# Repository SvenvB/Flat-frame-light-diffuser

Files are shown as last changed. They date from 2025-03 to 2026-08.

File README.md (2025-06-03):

# Flat Frame Light Diffuser for the Orion SpaceProbe 130ST
A simple white light source and custom mount for capturing flat frames with the Orion SpaceProbe 130ST telescope. Most of the materials I had lying around, but you can likely build it for around **$15**.

I'm using the [Orion SpaceProbe 130ST telescope](https://www.highpointscientific.com/orion-spaceprobe-130st-short-tube-eq-reflector-telescope) with a [ZWO ASI224MC](https://www.zwoastro.com/product/zwo-asi224mc/) CMOS imaging camera, and I enjoy deep-sky imaging without breaking the bank.

While dark frames are easy to take with the dust cap on, I was looking for a convenient and budget-friendly way to make **flat frames**. I usually shoot early in the evening and don't have twilight available. While placing a white t-shirt over the telescope and using a [laptop screen](https://practicalastrophotography.com/a-brief-guide-to-calibration-frames/) is one option, I wanted a more straightforward and reusable solution. Hence, this flat frame light diffuser for the Orion SpaceProbe 130ST.

The Flat Frame Light Diffuser is operated on the same 12V battery source I use for my star-tracker.

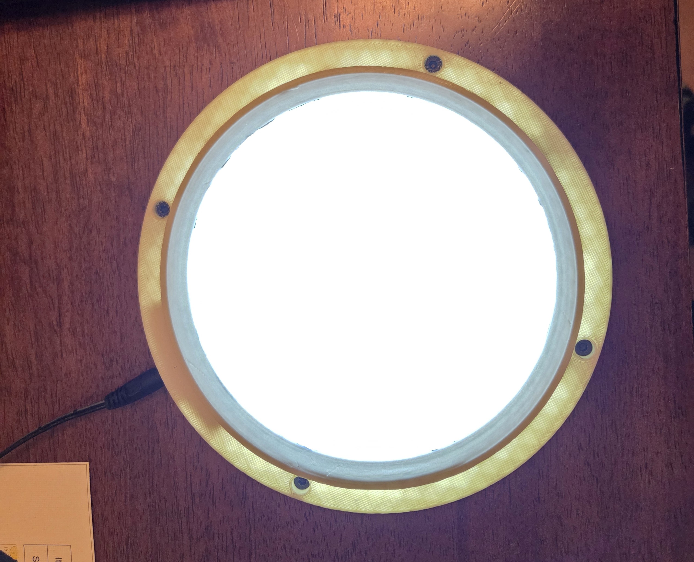
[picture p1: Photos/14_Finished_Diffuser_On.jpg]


---

## Materials

* **Flexible 12V LED strip** – Ideally, use white LEDs with a balanced spectrum. I used this [AliExpress LED strip](https://www.aliexpress.us/item/3256803152712901.html) I already had (probably not ideal for high fidelity calibration).
* **2× 1/4" round plexiglass sheets, 6-inch diameter** – [Example](https://www.amazon.com/dp/B09ZSYX99P). You could also use an opaque acrylic sheet to avoid needing a t-shirt for diffusion. You can use only one (thicker) sheet, just make sure that your LED strips will fit on the perimeter.
* **White t-shirt** – For diffusing light (if you're using clear plexiglass).
* **Flexible plastic sheet** – To protect the t-shirt from getting dirty and to allow for easy cleaning.
* **Aluminum tape** – [Link](https://www.amazon.com/dp/B0B6NDFXPN) - to reflect and contain light.
* **12V DC power source** – I used this [8×AA battery holder with DC barrel jack](https://www.amazon.com/DKARDU-Battery-Holder-Plastic-Arduino/dp/B09PH35NNX) that I already had for my EQ-mount motor.
* **Female DC barrel jack** – [Link](https://www.amazon.com/California-JOS-Breadboard-Friendly-Mounting-Female/dp/B09ZBN38FS)
* **3D printer and filament**
* **4× M4×16mm bolts + nuts**

---

## Instructions

### 1. Cut the LED strip

Stack the two acrylic sheets and cut the LED strip to the correct length. I used two sheets so the height of the resulting cylinder would be greater than the width of the LED strip.

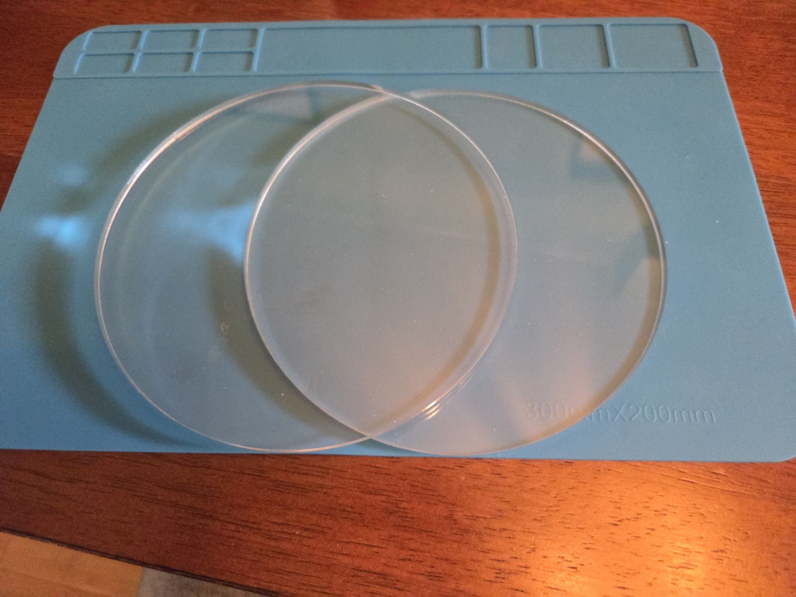
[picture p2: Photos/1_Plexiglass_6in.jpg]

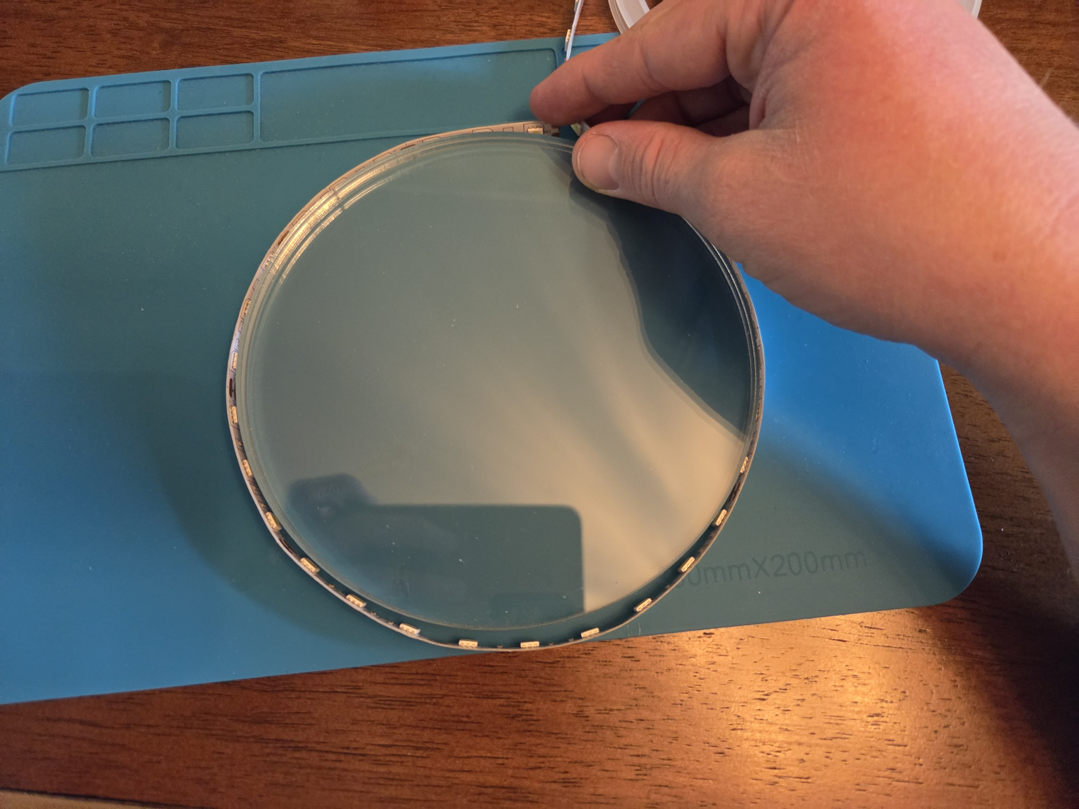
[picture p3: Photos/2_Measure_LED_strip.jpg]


---

### 2. Apply the aluminum tape

Neatly apply aluminum tape to one side of the stack. Try to keep it flat to avoid wrinkles and light hotspots. Cut the tape long enough so that it can wrap around the sides and help secure the LED strip.

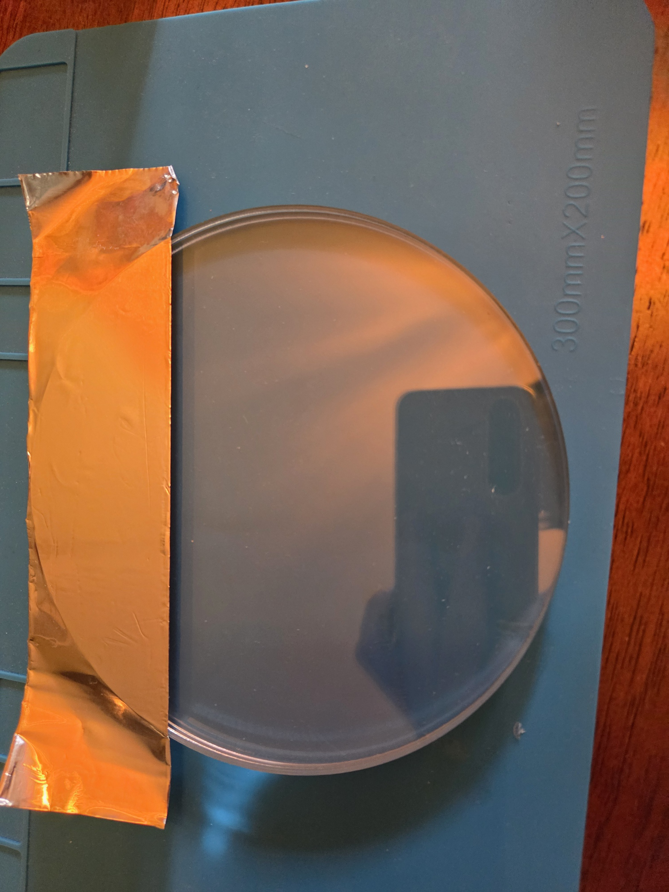
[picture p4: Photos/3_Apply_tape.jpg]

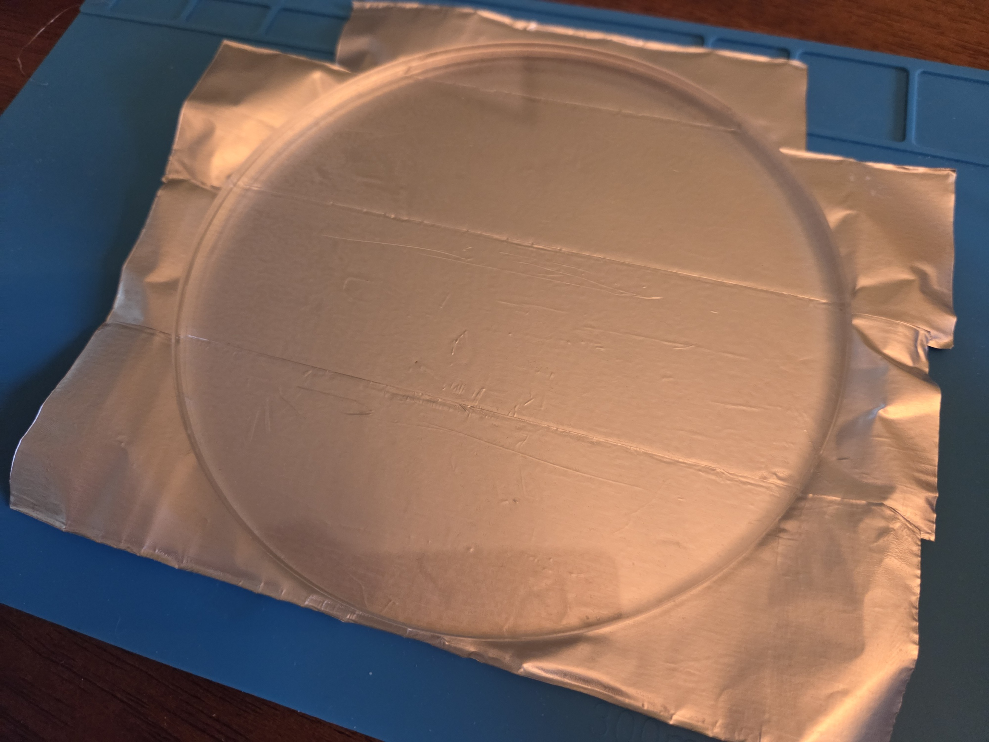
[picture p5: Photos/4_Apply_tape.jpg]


---

### 3. Tape the LED strip

Attach the LED strip to the side of the acrylic stack using the aluminum tape.

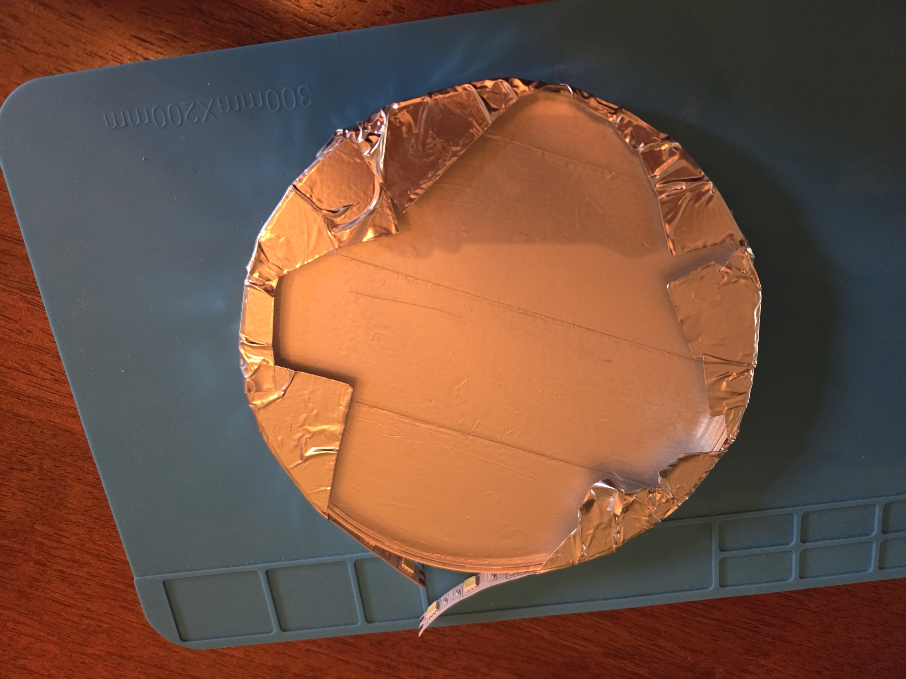
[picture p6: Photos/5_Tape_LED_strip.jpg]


---

### 4. Trim excess tape

Trim any excess tape from the top of the acrylic sheets using a knife.

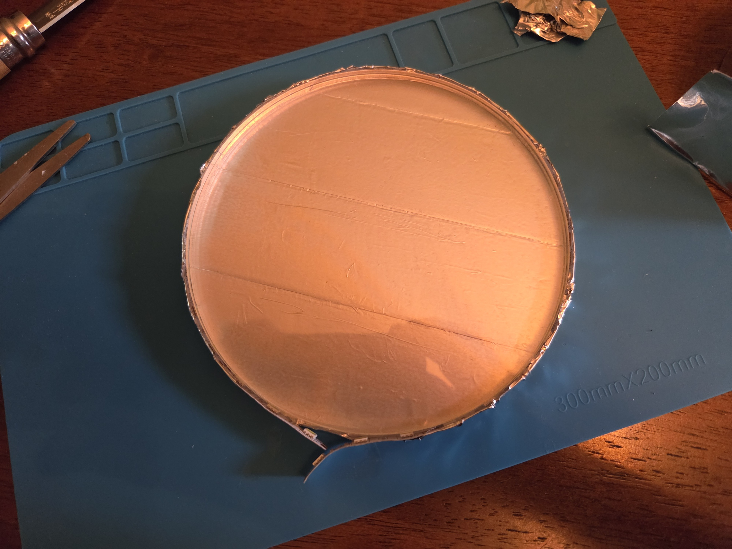
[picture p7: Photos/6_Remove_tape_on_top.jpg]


---

### 5. Solder the power cable

Solder the power cable to the LED strip. The cable only needs to be a few centimeters long since the female DC jack will be integrated into the mount. Also solder the female power jack.

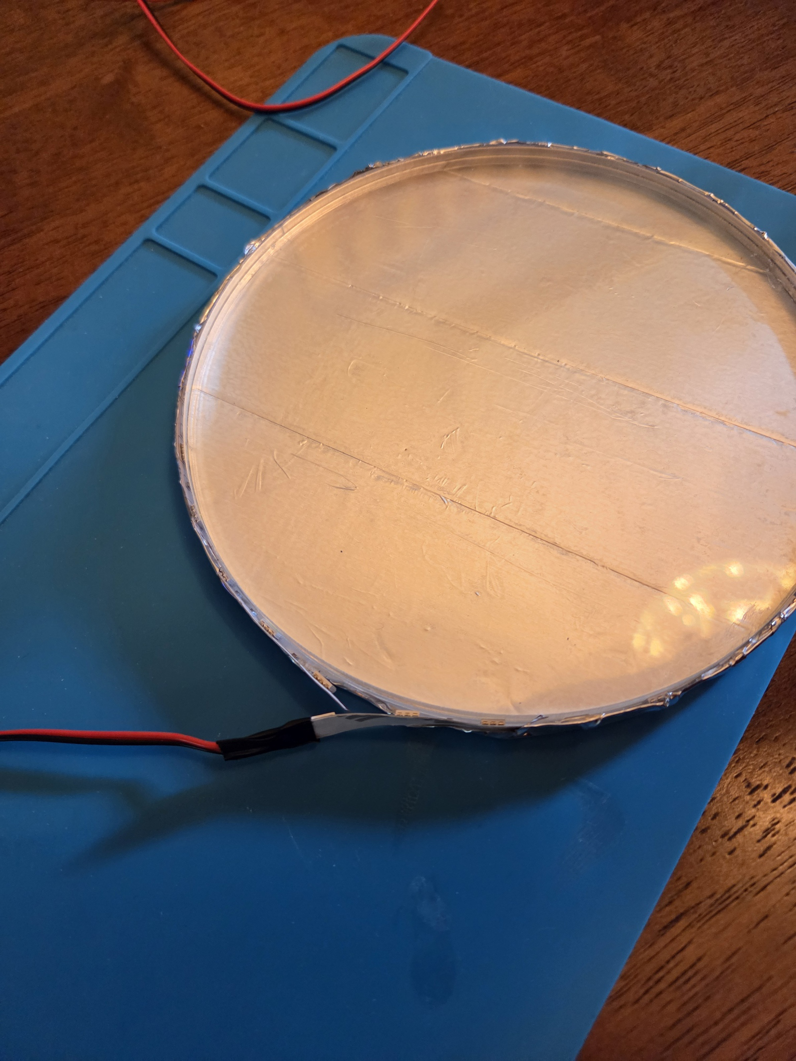
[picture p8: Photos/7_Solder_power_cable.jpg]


---

### 6. Attach the white t-shirt

This step might not be necessary if you’re using opaque acrylic sheets. For clear sheets, use a white t-shirt to diffuse the light. Cut it into a square or circle, stretch it over the diffuser, and secure it using aluminum tape on the backside. I used two layers of t-shirt to improve diffusion.

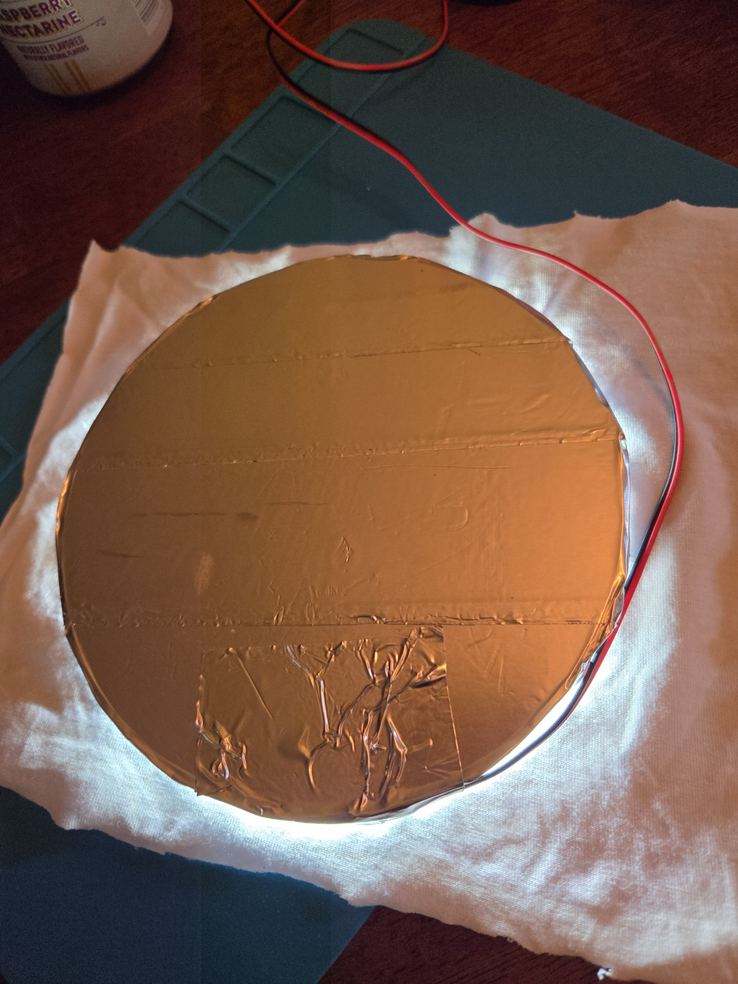
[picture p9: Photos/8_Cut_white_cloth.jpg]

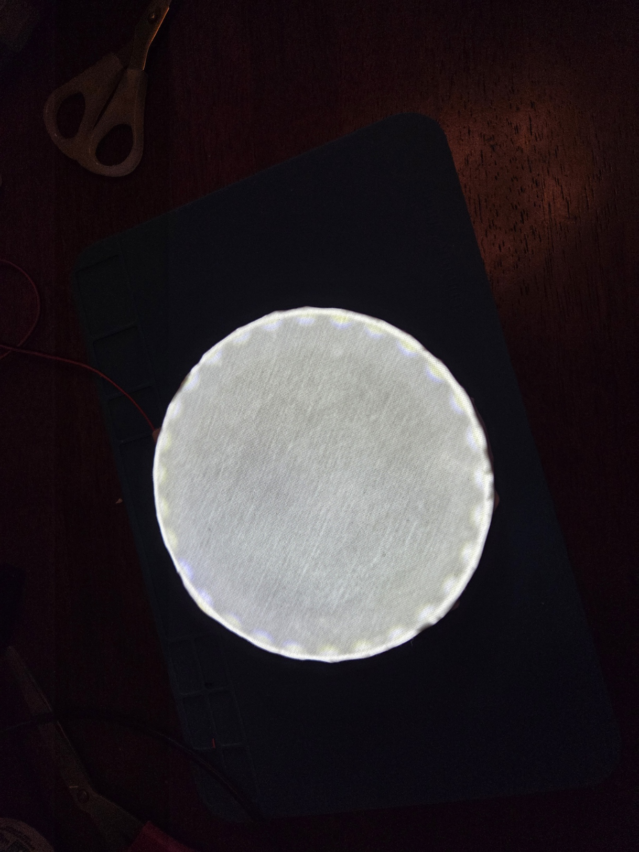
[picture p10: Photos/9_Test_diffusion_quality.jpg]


---

### 7. Make and install the mount

3D print the [mount](https://github.com/SvenvB/Flat-frame-light-diffuser/blob/main/CAD/FlatFrameDiffuser-Mount.stl) and apply aluminum tape around the inner rim to reflect light from the LEDs, as shown below.

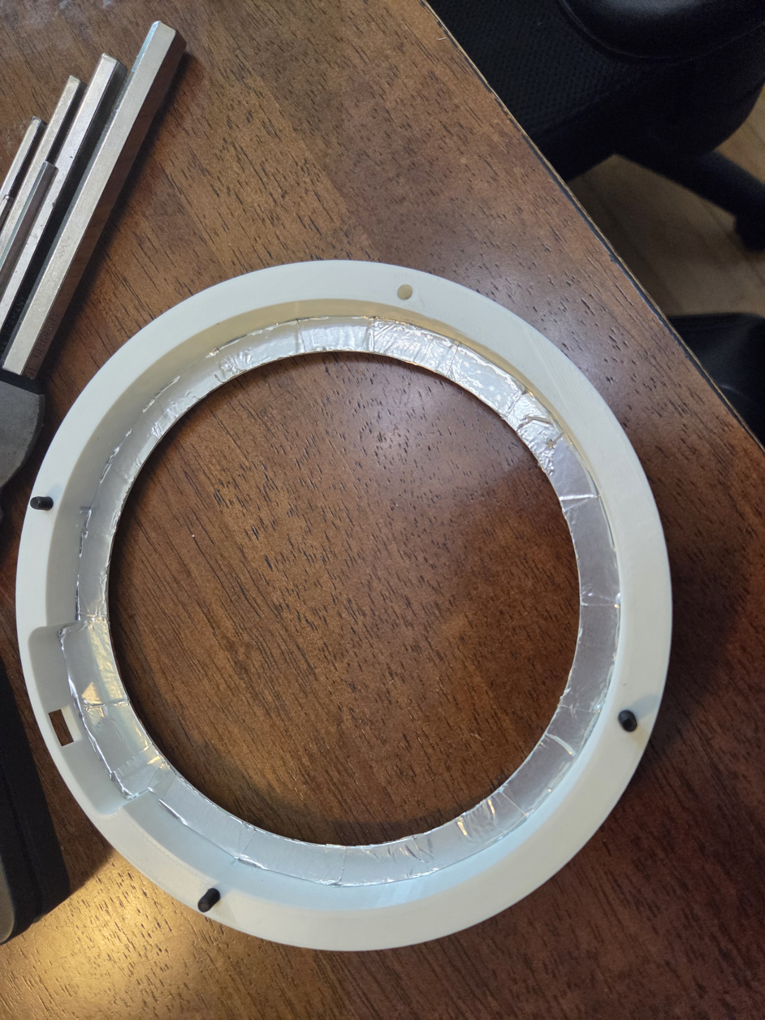
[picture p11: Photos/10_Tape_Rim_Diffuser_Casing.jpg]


Cut a thin plastic sheet in a circle that will fit in the mount, to protect the white t-shirt from getting dirty. Then mount the diffuser into the printed part. I used a hot glue gun to secure the female DC power jack in place.

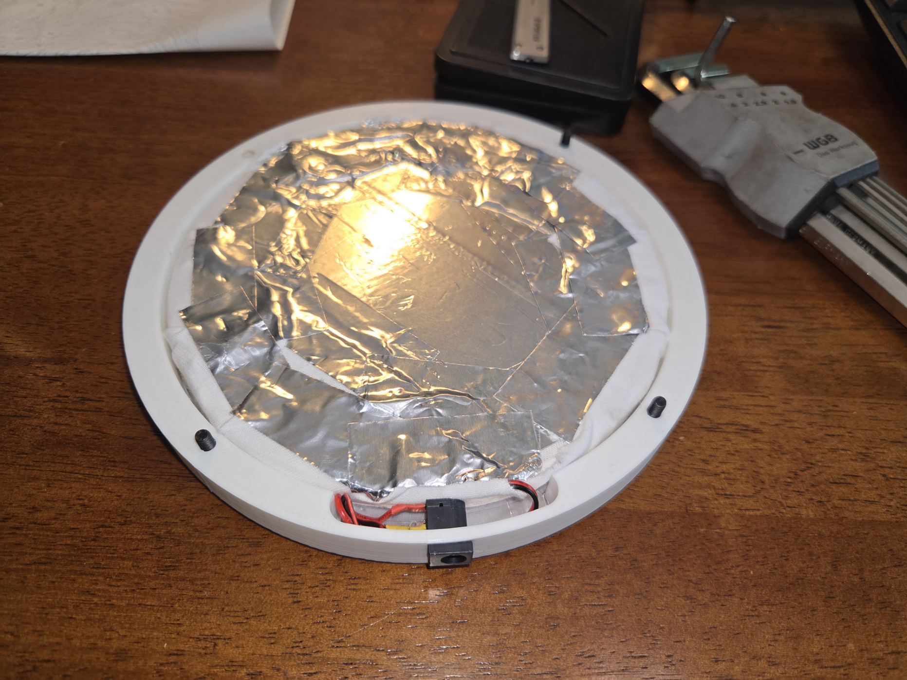
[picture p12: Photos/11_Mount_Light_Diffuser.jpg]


3D print the [backside cap](https://github.com/SvenvB/Flat-frame-light-diffuser/blob/main/CAD/FlatFrameDiffuser-Cap.stl) which can be secured to the mount with M4 bolts and nuts. Also find the [FreeCAD project](https://github.com/SvenvB/Flat-frame-light-diffuser/blob/main/CAD/FlatFrameDiffuser.FCStd) to remove the *Gingerbread Technologies* branding if desired.

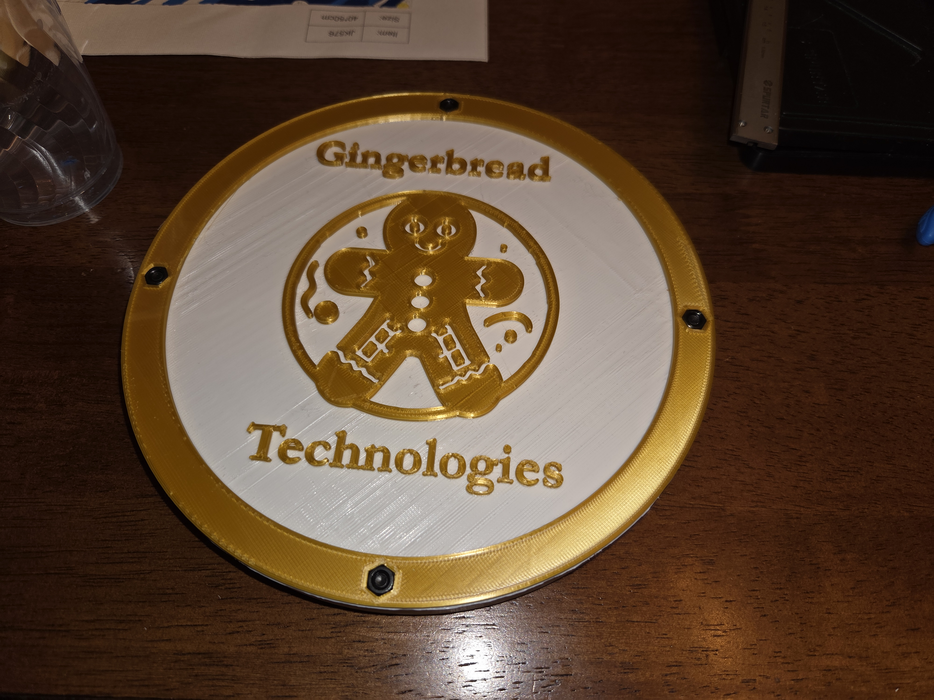
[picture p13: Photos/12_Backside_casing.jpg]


### 8. Finished Project
Enjoy your DIY Flat Frame Light Diffuser!

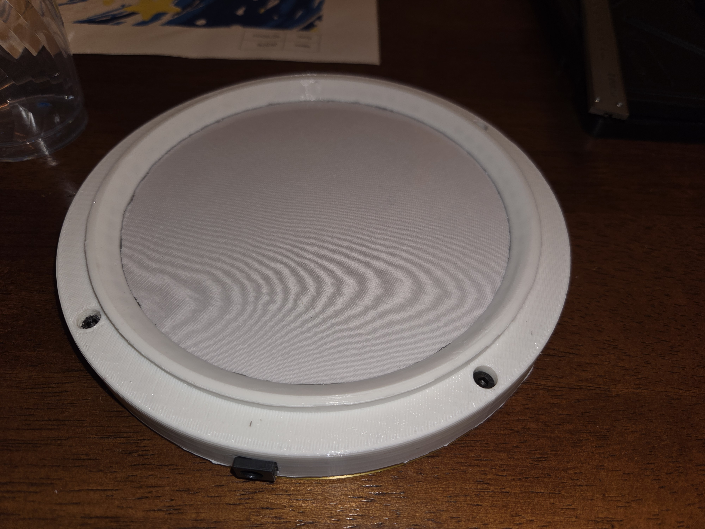
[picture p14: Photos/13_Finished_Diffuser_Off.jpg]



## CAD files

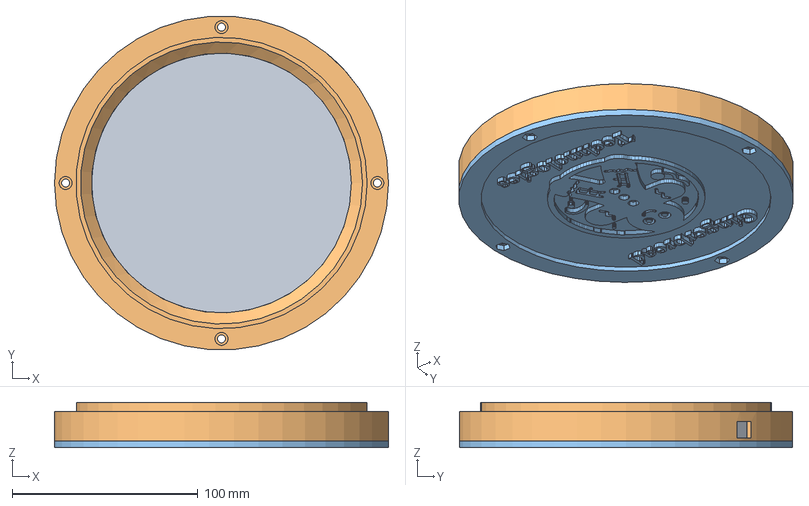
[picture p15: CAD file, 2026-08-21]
CAD/FlatFrameDiffuser.FCStd
180.0 x 179.5 x 24.5 mm
Diffuser001

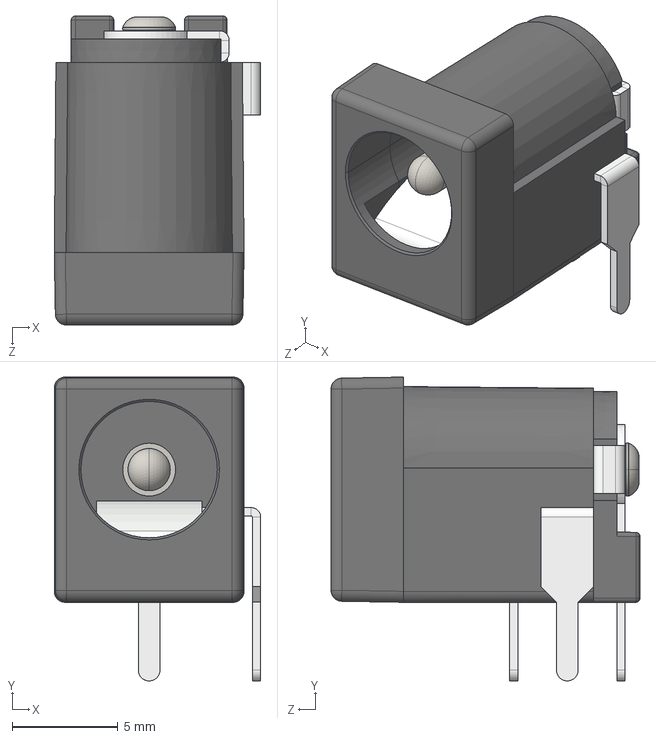
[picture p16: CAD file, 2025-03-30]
CAD/DC Power Jack 5.5mm x 2.1mm.STEP
9.77 x 14.4 x 14.6 mm

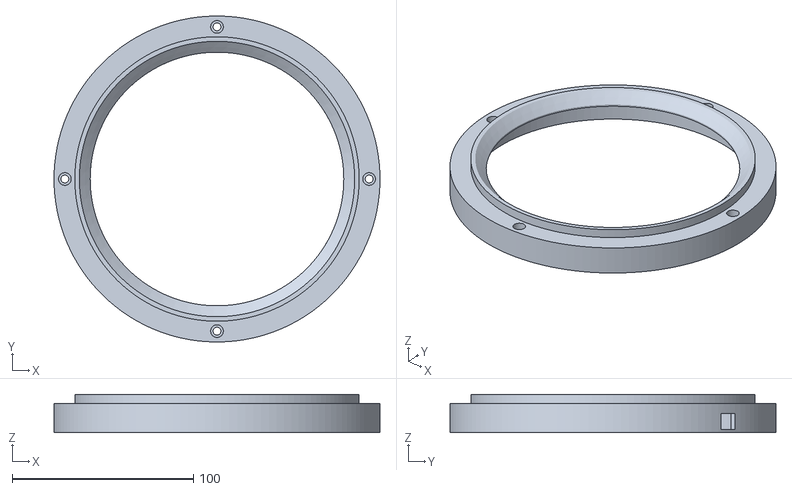
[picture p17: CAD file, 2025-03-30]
CAD/FlatFrameDiffuser-Mount.stl
180.0 x 179.9 x 21.0

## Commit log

2025-03-30 Added Photo's and CAD files
    [DC Power Jack 5.5mm x 2.1mm.STEP, FlatFrameDiffuser-Mount.stl]
2025-06-03 Added final assembly pictures
2026-08-21 Updated CAD
    [FlatFrameDiffuser.FCStd]
